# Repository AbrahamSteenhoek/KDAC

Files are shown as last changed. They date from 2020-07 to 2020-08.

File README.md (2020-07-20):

# KDAC
Keychain-sized DAC based on [Erik Soosalu's GrubDAC](http://www.diyforums.org/GrubDAC/GrubDACoverview.php)

The schematic is taken almost entirely from Soosalu's design, but the PCB layout has been modified to fit a smaller "key-chain sized" form factor.

Uses a USB-C connector instead of USB-mini B

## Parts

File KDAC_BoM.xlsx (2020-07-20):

GrubDAC_MOD |  |  |  |  | http://www.diyforums.org/GrubDAC/GrubDACoverview.php
Abraham Steenhoek
Bill of Materials |  |  |  |  |  | Manufacturer |  | Digikey Info |  | Product Cost [$]
Qty | RefID | Technical Description | SMT or TH | Package | Datasheet | Name | Mfgr Part No | Digi-key Part # | Web Address | Unit | Total | Total Cost [$]
1 | U1 | Audio Audio Signal Processor 2 Channel 32-TQFP (7x7) | SMT | TQFP-32 | https://www.ti.com/general/docs/suppproductinfo.tsp?distId=10 | Texas Instruments | PCM2706CPJTR | 296-40481-1-ND | https://www.digikey.com/product-detail/en/texas-instruments/PCM2706CPJTR/296-40481-1-ND/5178358 | $7.04 | $7.04 | $22.36
1 | U2 | Linear Voltage Regulator IC 1 Output 200mA SOT-23-5 | SMT | SOT-23-5 | https://media.digikey.com/pdf/Data%20Sheets/Texas%20Instruments%20PDFs/TPS793_Rev2015.pdf | Texas Instruments | TPS79333DBVR | 296-12961-1-ND | https://www.digikey.com/product-detail/en/texas-instruments/TPS79333DBVR/296-12961-1-ND/476149 | $0.73 | $0.73
1 | U3 | DAC, Audio 24 b 192k I²S 16-TSSOP | SMT | 16-TSSOP | https://d3uzseaevmutz1.cloudfront.net/pubs/proDatasheet/WM8524_v4.1.pdf | Cirrus Logic Inc. | WM8524CGEDT/R | WM8524CGEDT/RCT-ND | https://www.digikey.com/product-detail/en/cirrus-logic-inc/WM8524CGEDT-R/WM8524CGEDT-RCT-ND/5036756 | $1.98 | $1.98
1 | X1 | 12MHz XO (Standard) HCMOS Oscillator 3.3V Enable/Disable 4-SMD, No Lead | SMT | 4-SMD, No Lead | https://abracon.com/Oscillators/ASV.pdf | Abracon LLC | ASV-12.000MHZ-EJ-T | 535-9309-1-ND | https://www.digikey.com/product-detail/en/abracon-llc/ASV-12-000MHZ-EJ-T/535-9309-1-ND/675730 | $1.73 | $1.73
6 | C3, C4, C6, C7, C12, C13 | 1µF -20%, +80% 16V Ceramic Capacitor Y5V (F) 0805 (2012 Metric) | SMT | 0805 | https://content.kemet.com/datasheets/KEM_C1005_Y5V_SMD.pdf | KEMET | C0805C105Z4VACTU | 399-8011-1-ND | https://www.digikey.com/product-detail/en/kemet/C0805C105Z4VACTU/399-8011-1-ND/3471734 | $0.12 | $0.72
2 | C2, C8 | 10000pF ±10% 50V Ceramic Capacitor X7R 0805 (2012 Metric) | SMT | 0805 | https://content.kemet.com/datasheets/KEM_C1002_X7R_SMD.pdf | KEMET | C0805C103K5RACTU | 399-1158-1-ND | https://www.digikey.com/product-detail/en/kemet/C0805C103K5RACTU/399-1158-1-ND/411433 | $0.13 | $0.26
2 | C9, C14 | 2.2µF -20%, +80% 16V Ceramic Capacitor Y5V (F) 0805 (2012 Metric) | SMT | 0805 | https://www.yageo.com/upload/media/product/productsearch/datasheet/mlcc/UPY-GPHC_Y5V_6.3V-to-50V_9.pdf | Yageo | CC0805ZRY5V7BB225 | 311-1463-1-ND | https://www.digikey.com/product-detail/en/murata-electronics/GRM21BR71E225KE11L/490-14467-1-ND/6606928 | $0.19 | $0.38
2 | C16, C17 | 0.015µF Film Capacitor 40V 63V Polypropylene (PP) Radial | TH | 5mm Lead Spacing | https://content.kemet.com/datasheets/KEM_C1002_X7R_SMD.pdf | WIMA | FKP2C021501I00JSSD | 1928-1224-ND | https://www.digikey.com/product-detail/en/wima/FKP2C021501I00JSSD/1928-1224-ND/9370176 | $0.54 | $1.08 | Use ceramics as alternative (loss in audio quality)
2 | C10, C11 | 4.7µF ±20% 25V Ceramic Capacitor X5R 0805 (2012 Metric) | SMT | 0805 | https://search.murata.co.jp/Ceramy/image/img/A01X/G101/ENG/GRM219R61E475MA73-01.pdf | Murata | GRM219R61E475MA73D | 490-14644-1-ND | https://www.digikey.com/product-detail/en/murata-electronics/GRM219R61E475MA73D/490-14644-1-ND/6606250 | $0.25 | $0.50
2 | R1, R6 | 1.5 kOhms ±1% 0.25W, 1/4W Chip Resistor 1206 (3216 Metric) Automotive AEC-Q200 Thick Film | SMT | 1206 | https://www.vishay.com/docs/20035/dcrcwe3.pdf | Vishay Dale | CRCW12061K50FKEA | 541-1.50KFCT-ND | https://www.digikey.com/product-detail/en/vishay-dale/CRCW12061K50FKEA/541-1.50KFCT-ND/1181778 | $0.10 | $0.20
3 | R2, R3, R7 | 22 Ohms ±1% 0.25W, 1/4W Chip Resistor 1206 (3216 Metric) Automotive AEC-Q200 Thick Film | SMT | 1206 | https://www.vishay.com/docs/20035/dcrcwe3.pdf | Vishay Dale | CRCW120622R0FKEA | 541-22.0FCT-ND | https://www.digikey.com/product-detail/en/vishay-dale/CRCW120622R0FKEA/541-22.0FCT-ND/1181568 | $0.10 | $0.30
1 | R4 | 4.7 Ohms ±1% 0.25W, 1/4W Chip Resistor 1206 (3216 Metric) Automotive AEC-Q200, Current Sense Thick Film | SMT | 1206 | https://www.vishay.com/docs/20035/dcrcwe3.pdf | Vishay Dale | ERJ-8RQF4R7V | P4.7RCT-ND | https://www.digikey.com/product-detail/en/panasonic-electronic-components/ERJ-8RQF4R7V/P4.7RCT-ND/250343 | $0.37 | $0.37
1 | R5 | 560 Ohms ±1% 0.25W, 1/4W Chip Resistor 1206 (3216 Metric) Automotive AEC-Q200 Thick Film | SMT | 1206 | https://www.te.com/commerce/DocumentDelivery/DDEController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 | TE Connectivity | CRGCQ1206F560R | A129807CT-ND | https://www.digikey.com/product-detail/en/te-connectivity-passive-product/CRGCQ1206F560R/A129807CT-ND/8577639 | $0.10 | $0.10
3 | L1, L2, L3 | 600 Ohms @ 100MHz 1 Power Line Ferrite Bead 1206 (3216 Metric) 1.5A 80mOhm | SMT | 1206 | https://www.murata.com/en-us/products/productdata/8796739698718/ENFA0006.pdf | Murata | BLM31PG601SN1L | 490-1057-1-ND | https://www.digikey.com/product-detail/en/murata-electronics/BLM31PG601SN1L/490-1057-1-ND/584503 | $0.31 | $0.93
3 | C1, C5, C15 | 220µF 35V Aluminum Electrolytic Capacitors Radial, Can - SMD 2000 Hrs @ 85°C | SMT | 0.327" L x 0.327" W (8.30mm x 8.30mm) | https://media.digikey.com/pdf/Data%20Sheets/Panasonic%20Electronic%20Components/S_Series,Type_V_Rev2018.pdf | Panasonic | EEE-1VA221UP | PCE3955CT-ND | https://www.digikey.com/product-detail/en/panasonic-electronic-components/EEE-1VA221UP/PCE3955CT-ND/766331 | $0.61 | $1.83
2 | R8, R9 | 110 Ohms ±1% 0.25W, 1/4W Through Hole Resistor Axial Flame Retardant Coating, Moisture Resistant, Safety Metal Film | TH | Axial | https://www.vishay.com/docs/31018/cmfind.pdf | Vishay Dale | CMF50110R00FHEB | CMF110QFCT-ND | https://www.digikey.com/product-detail/en/vishay-dale/CMF50110R00FHEB/CMF110QFCT-ND/1554463 | $0.67 | $1.34
1 | LED1 | Amber 592nm LED Indication - Discrete 1.9V 0805 (2012 Metric) | SMT | 0805 | https://docs.broadcom.com/docs/AV02-0112EN | Broadcom Limited | HSMA-C170 | 516-1431-1-ND | https://www.digikey.com/product-detail/en/broadcom-limited/HSMA-C170/516-1431-1-ND/637755 | $0.46 | $0.46
1 | USB1 | USB-C (USB TYPE-C) USB 2.0 Receptacle Connector 24 (16+8 Dummy) Position Surface Mount, Right Angle; Through Hole | SMT | Custom | https://gct.co/files/drawings/usb4110.pdf | GCT | USB4110-GF-A | 2073-USB4110-GF-A-1-ND | https://www.digikey.com/product-detail/en/gct/USB4110-GF-A/2073-USB4110-GF-A-1-ND/10384548 | $1.37 | $1.37
1 | J2 | 3.50mm (0.141", 1/8", Mini Plug) - Headphone Phone Jack Stereo (3 Conductor, TRS) Connector Solder | SMT | Custom | https://www.cuidevices.com/product/resource/sj-352x-smt.pdf | CUI Devices | SJ-3524-SMT-TR | CP-3524SJCT-ND | https://www.digikey.com/product-detail/en/cui-devices/SJ-3524-SMT-TR/CP-3524SJCT-ND/669705 | $1.04 | $1.04
Alternate Parts
1 | USB1? | USB - micro B USB 2.0 Receptacle Connector 5 Position Surface Mount, Right Angle | SMT | Custom | https://www.amphenol-icc.com/media/wysiwyg/files/drawing/10118192.pdf | Amphenol | 10118192-0002LF | 609-5379-1-ND | https://www.digikey.com/product-detail/en/amphenol-icc-fci/10118192-0002LF/609-5379-1-ND/8555650 | $0.46

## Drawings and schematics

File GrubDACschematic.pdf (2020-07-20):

## GrubDAC rev e USB Section

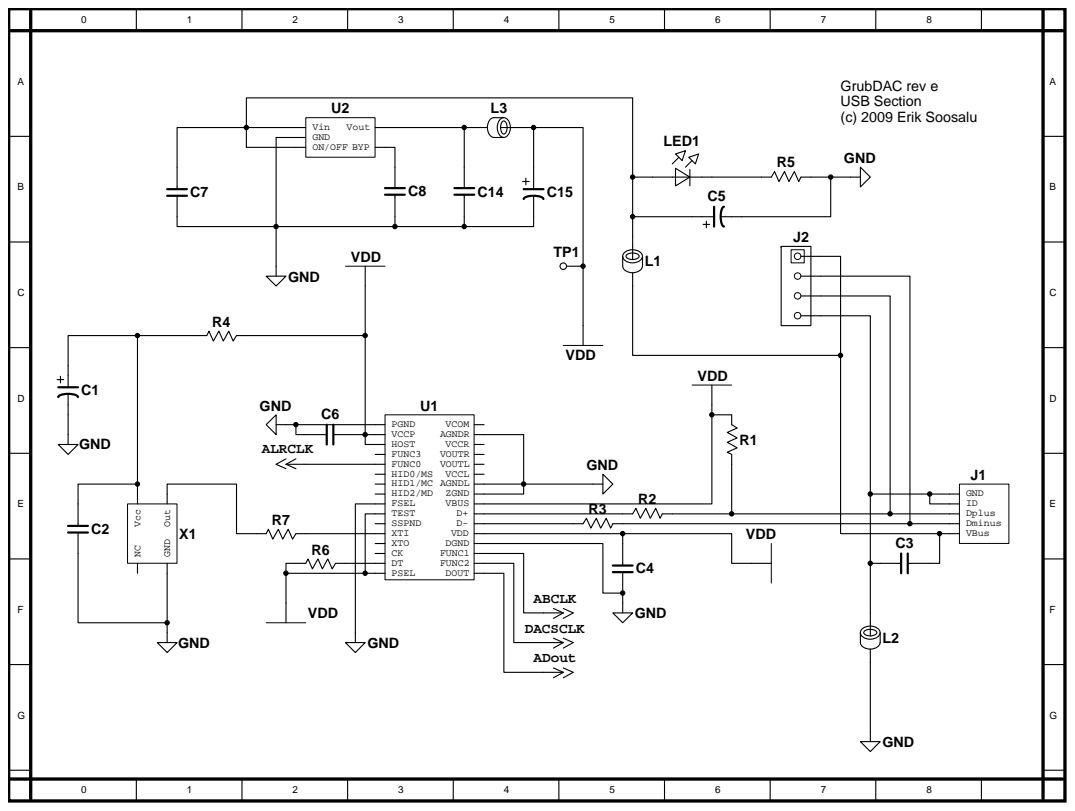
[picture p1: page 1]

C17

R9

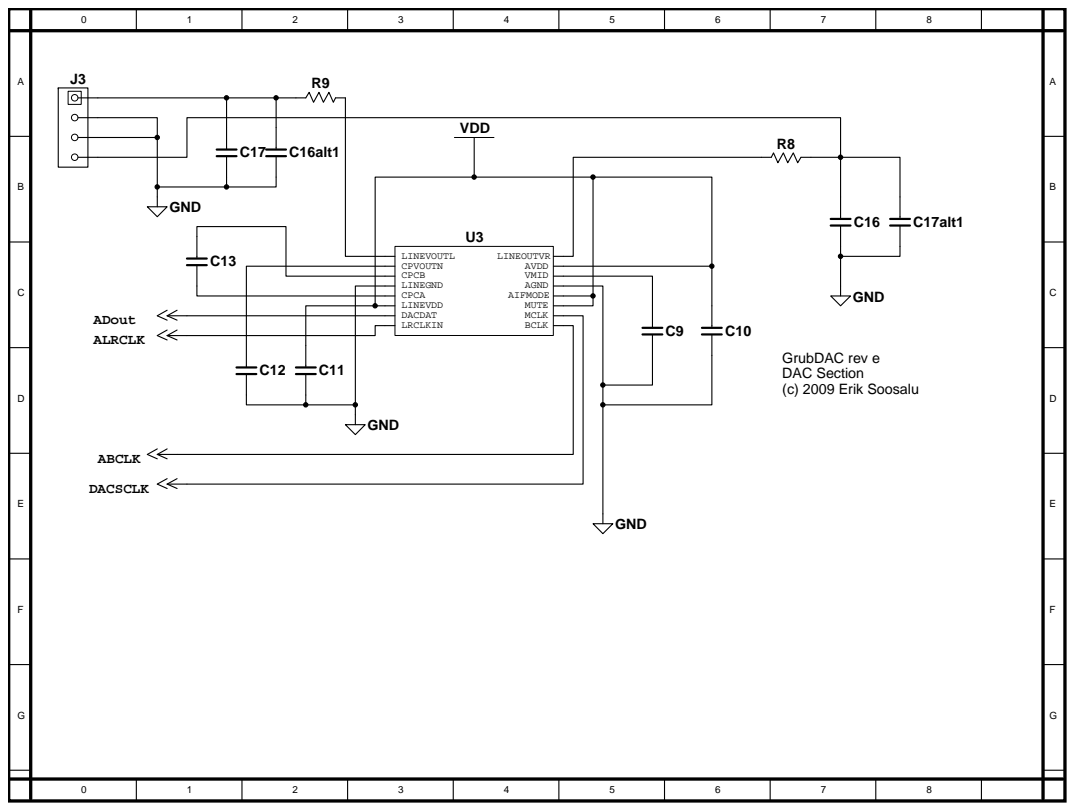
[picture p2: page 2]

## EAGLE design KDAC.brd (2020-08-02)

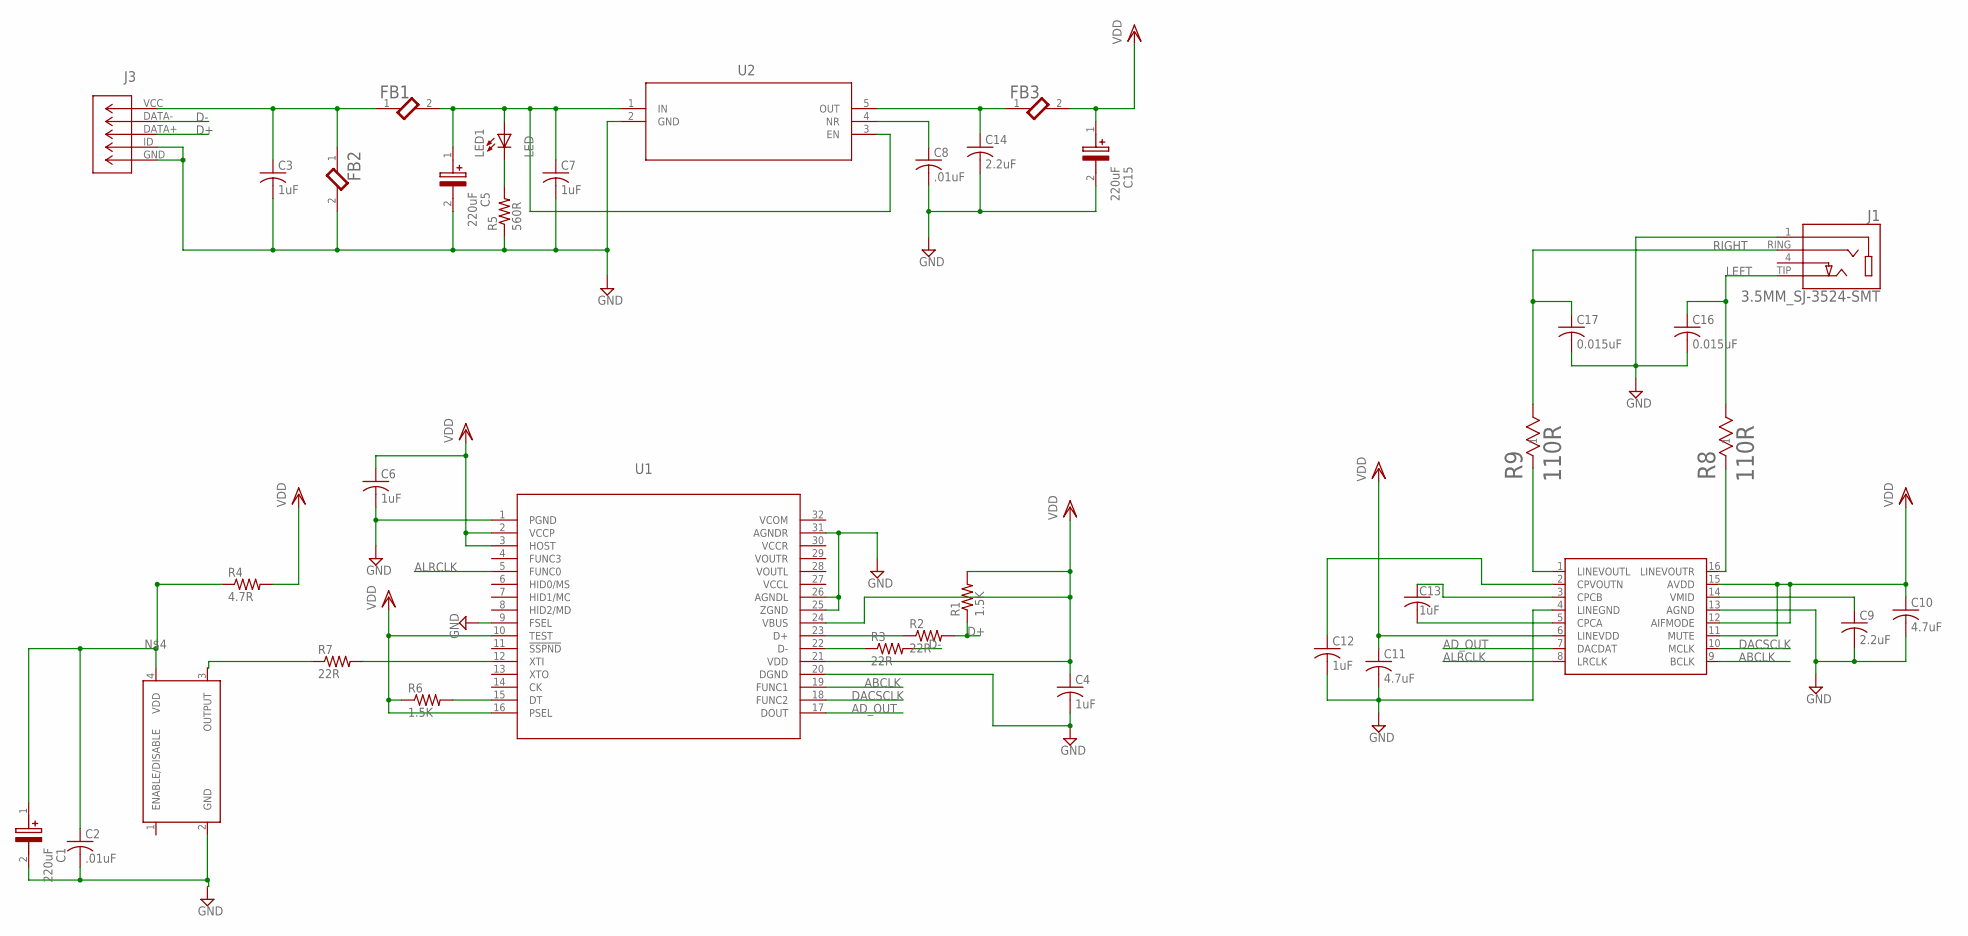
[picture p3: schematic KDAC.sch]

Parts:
C1, C5, C15: 220uF; CAPAE830X1050N
C2, C8: .01uF; C0805
C3, C4, C6, C7, C12, C13: 1uF; C0805
C9, C14: 2.2uF; C0805
C10, C11: 4.7uF; C0805
C16, C17: 0.015uF; C050-075X075
FB1, FB2, FB3: L_MURATA_BLM31PG601SN1LMURATA_BLM31PG601SN1L_0_2; MURATA_BLM31PG601SN1L_2
J1: 3.5MM_SJ-3524-SMT; CUI_SJ-3524-SMT
J3: USB-MICRO-B_10118192-0002LF; CONN_10118192-0002LF_AMP
LED1: LED; LED_2.54MM_0.5MM
R1, R6: 1.5K; R1206
R2, R3, R7: 22R; R1206
R4: 4.7R; R1206
R5: 560R; R1206
R8, R9: 110R; RES_CMF50
U1: PCM2706CPJTRPJT32-M; PJT32-M
U2: TPS79333DBVRDBV5_TEX-M; DBV5_TEX-M
U3: WM8524ALT; SOP65P640X110-16N
X1: ASV-12MHZ; ASV_12MHZ_4SMD-M

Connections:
ABCLK: U1.19 (FUNC1), U3.9 (BCLK)
AD_OUT: U1.17 (DOUT), U3.7 (DACDAT)
ALRCLK: U1.5 (FUNC0), U3.8 (LRCLK)
D+: J3.DATA+, R1.1, R2.2
D-: J3.DATA-, R3.2
DACSCLK: U1.18 (FUNC2), U3.10 (MCLK)
GND: C1.2 (-), C2.2, C3.2, C4.2, C5.2 (-), C6.2, C7.2, C8.2, C9.2, C10.2, C11.2, C12.2, C14.2, C15.2 (-), C16.2, C17.2, FB2.2, J1.1, J3.GND, J3.ID, R5.1, U1.1 (PGND), U1.9 (FSEL), U1.20 (DGND), U1.25 (ZGND), U1.26 (AGNDL), U1.31 (AGNDR), U2.2 (GND), U3.4 (LINEGND), U3.13 (AGND), X1.2 (GND)
LEFT: C16.1, J1.TIP (2), R8.2
unnamed: C3.1, FB1.1, FB2.1, J3.VCC
unnamed: C14.1, FB3.1, U2.5 (OUT)
unnamed: C5.1 (+), C7.1, FB1.2, LED1.ANODE (+), U2.1 (IN), U2.3 (EN)
unnamed: C1.1 (+), C2.1, R4.1, X1.4 (VDD)
unnamed: R7.2, U1.12 (XTI)
unnamed: R7.1, X1.3 (OUTPUT)
unnamed: LED1.CATHODE (-), R5.2
unnamed: C8.1, U2.4 (NR)
unnamed: R6.2, U1.15 (DT)
unnamed: R3.1, U1.22 (D-)
unnamed: R2.1, U1.23 (D+)
unnamed: C13.1, U3.3 (CPCB)
unnamed: C12.1, U3.2 (CPVOUTN)
unnamed: C9.1, U3.14 (VMID)
unnamed: C13.2, U3.5 (CPCA)
unnamed: R9.1, U3.1 (LINEVOUTL)
unnamed: R8.1, U3.16 (LINEVOUTR)
RIGHT: C17.1, J1.RING (3), R9.2
VCCL: U1.27 (VCCL)
VCCR: U1.30 (VCCR)
VCOM: U1.32 (VCOM)
VDD: C4.1, C6.1, C10.1, C11.1, C15.1 (+), FB3.2, R1.2, R4.2, R6.1, U1.2 (VCCP), U1.3 (HOST), U1.10 (TEST), U1.16 (PSEL), U1.21 (VDD), U1.24 (VBUS), U3.6 (LINEVDD), U3.11 (MUTE), U3.12 (AIFMODE), U3.15 (AVDD)

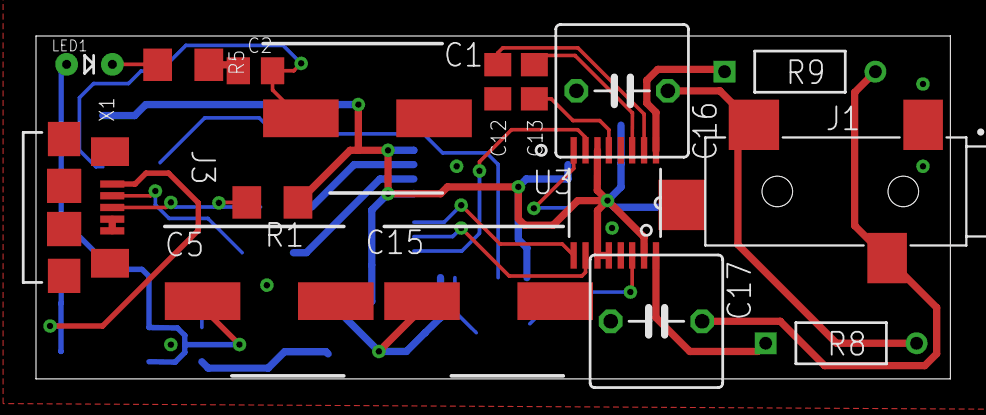
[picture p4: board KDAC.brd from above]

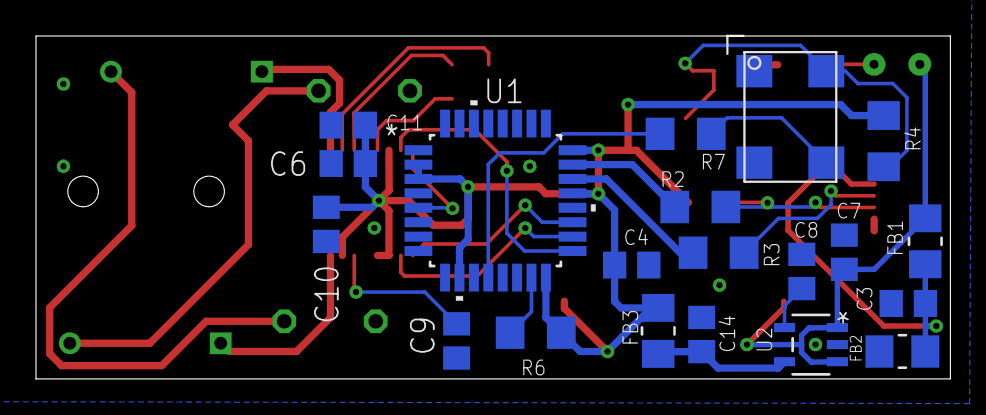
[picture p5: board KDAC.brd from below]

Board: 2 copper layers, 50.8 x 19.1 mm, 36 parts (20 on the bottom side), 27 nets.

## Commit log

2020-07-20 Bring files into GitHub
    [KDAC.brd, KDAC.sch, KDAC_BoM.xlsx]
2020-07-31 Switch usb c to usb micro b
    [KDAC.brd, KDAC.sch]

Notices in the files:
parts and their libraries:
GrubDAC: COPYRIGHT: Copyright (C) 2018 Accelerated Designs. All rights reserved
